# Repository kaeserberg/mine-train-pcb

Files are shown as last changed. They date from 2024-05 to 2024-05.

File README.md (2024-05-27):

# Le Train de la Mine - PCB

## Illustrations

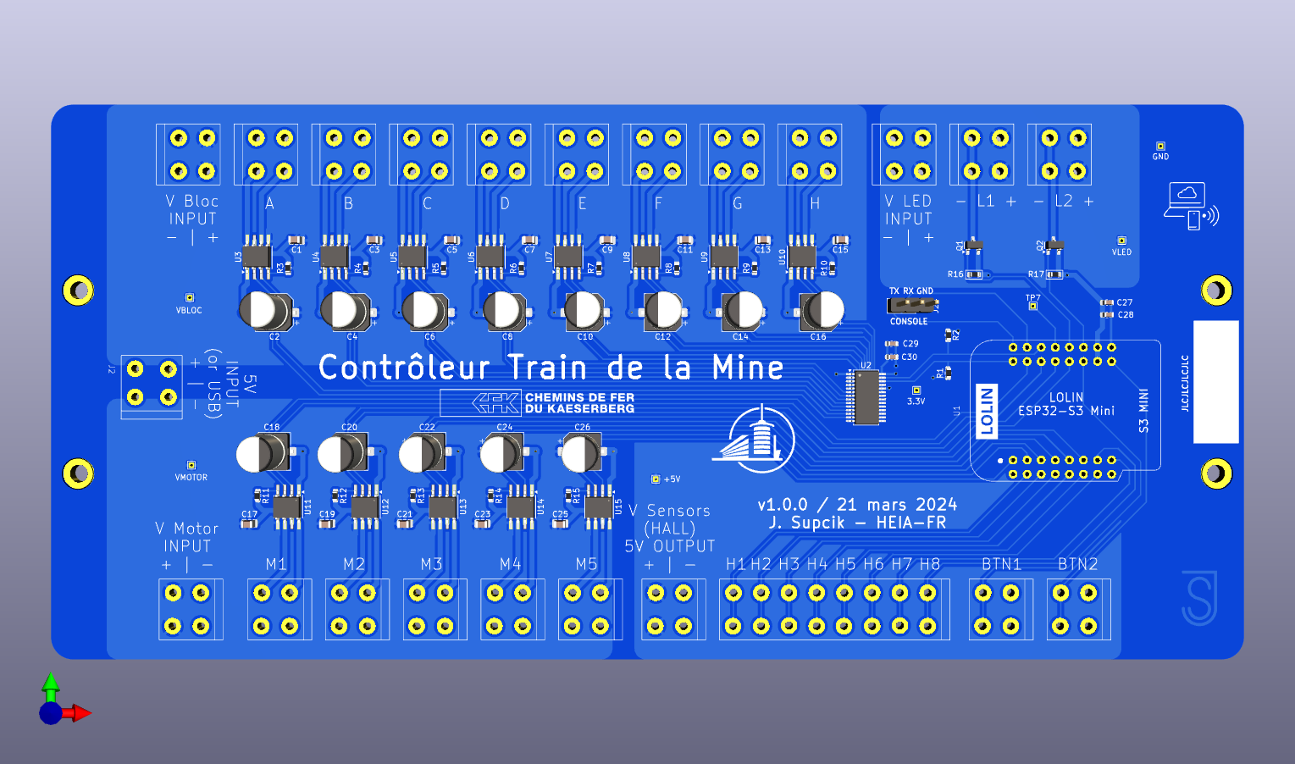
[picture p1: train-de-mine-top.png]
Dessus
<br/>
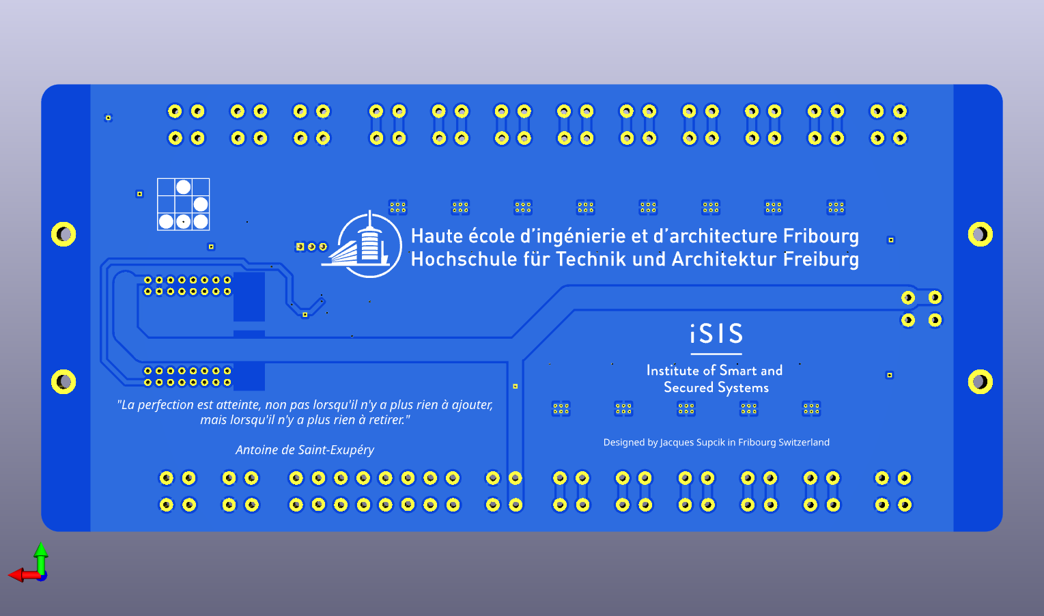
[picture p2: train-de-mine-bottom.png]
Desous


## Schéma

[Schéma électronique](train-de-mine-schematic.pdf)

## Commande de matériel

- [1 x 8p (1 x 12 pièces)](https://fr.aliexpress.com/item/1005005946834644.html)
- [3 x 2p (3 x 50 pièces)](https://fr.aliexpress.com/item/1005005946834644.html)
- [5x jeu de montage DRG-02](https://fr.aliexpress.com/item/32824633947.html)
- [5x rail DIN 30cm](https://fr.aliexpress.com/item/4001298414947.html)
- [5x ESP32-S3 Mini](https://fr.aliexpress.com/item/1005005449219195.html)
- [1x Connecteur femelle à 2x8 broches (50 pièces)](https://fr.aliexpress.com/item/32604411845.html)

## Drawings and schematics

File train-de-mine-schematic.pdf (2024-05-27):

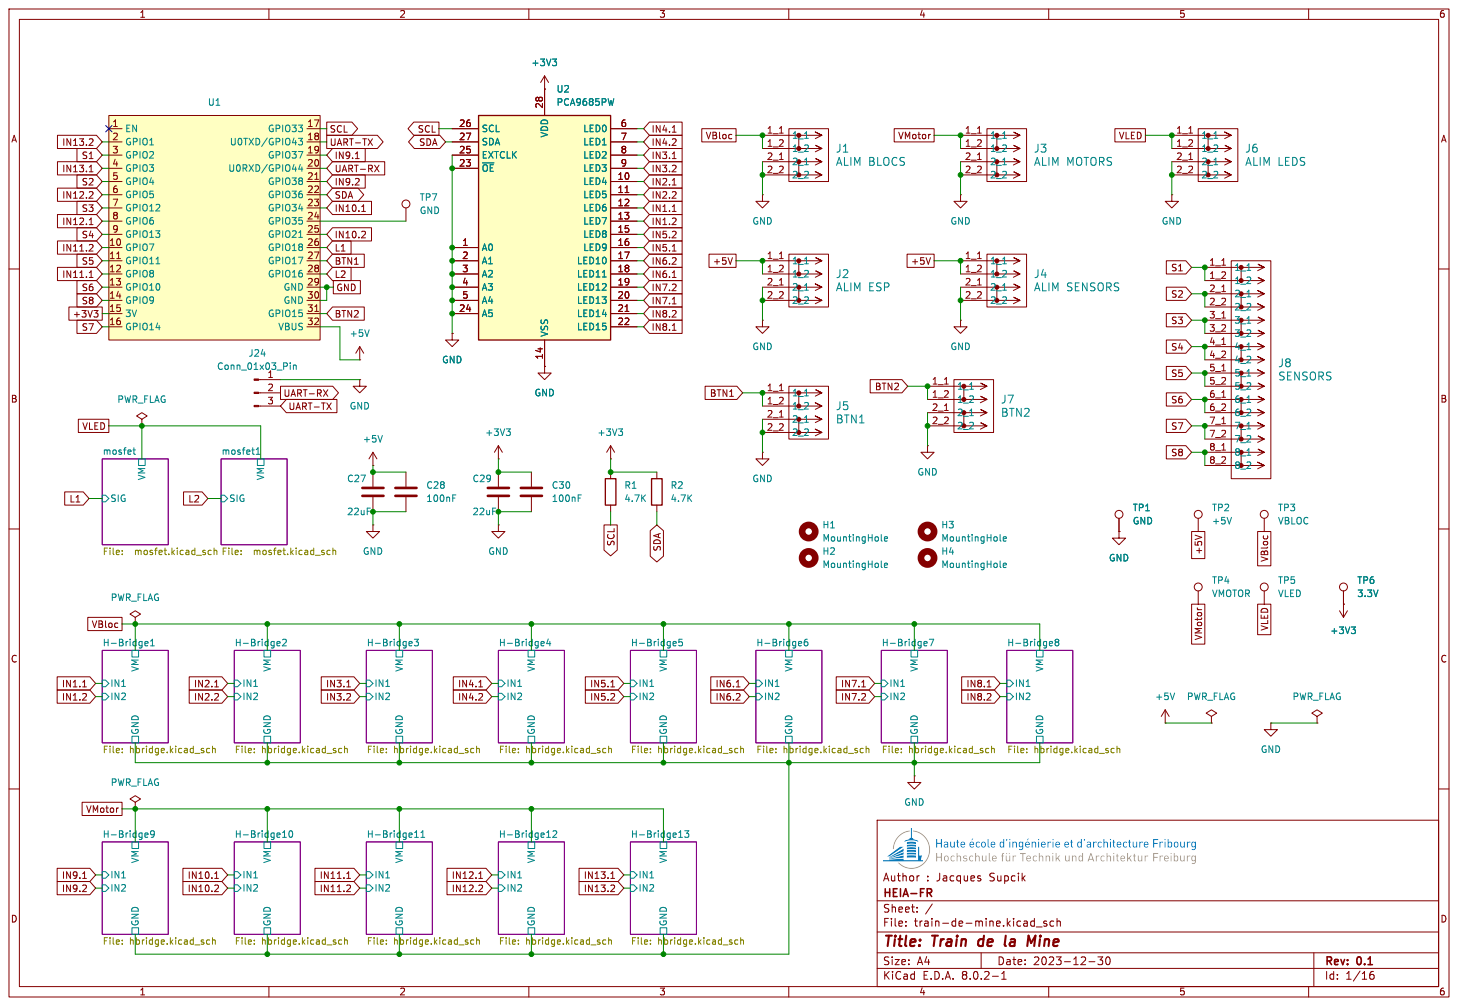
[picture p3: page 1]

Author : Jacques Supcik
File: train-de-mine.kicad_sch Sheet: / HEIA-FR

Id: 1/16 Title: Train de la Mine

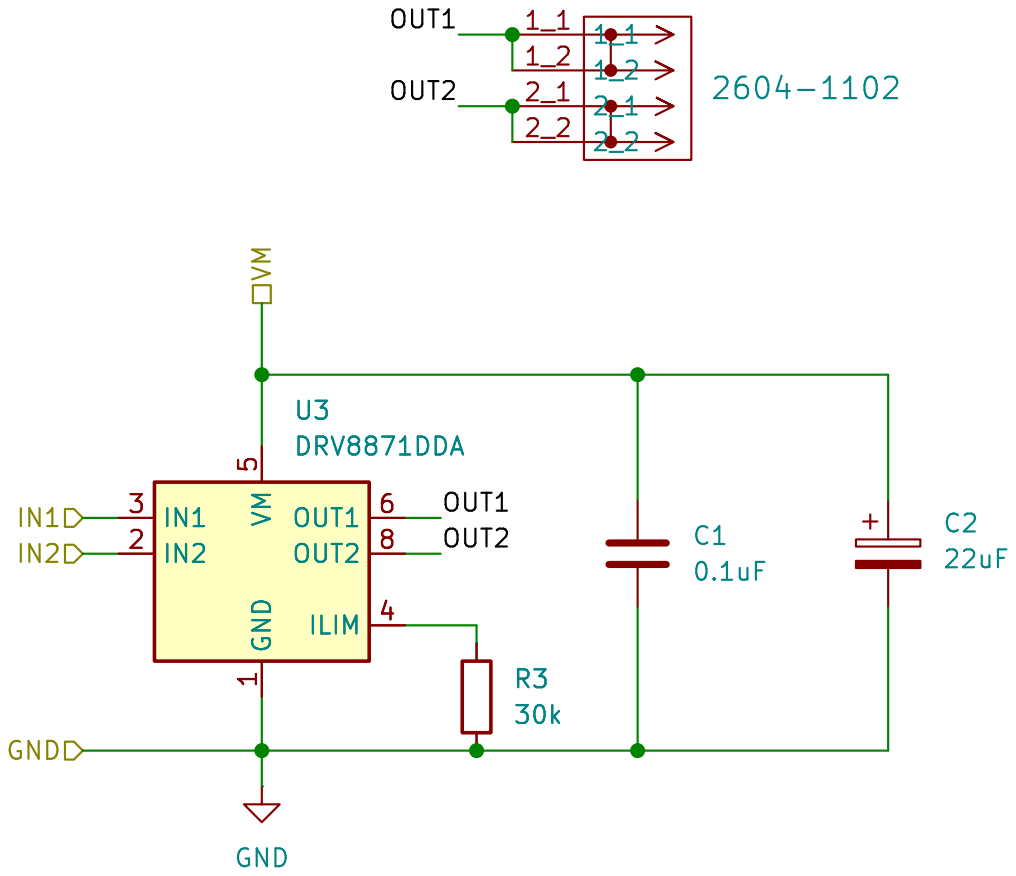
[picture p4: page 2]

Author: Jacques Supcik
File: hbridge.kicad_sch Sheet: /H-Bridge1/ HEIA-FR

Id: 2/16 Title: Train de la Mine : H-Bridge

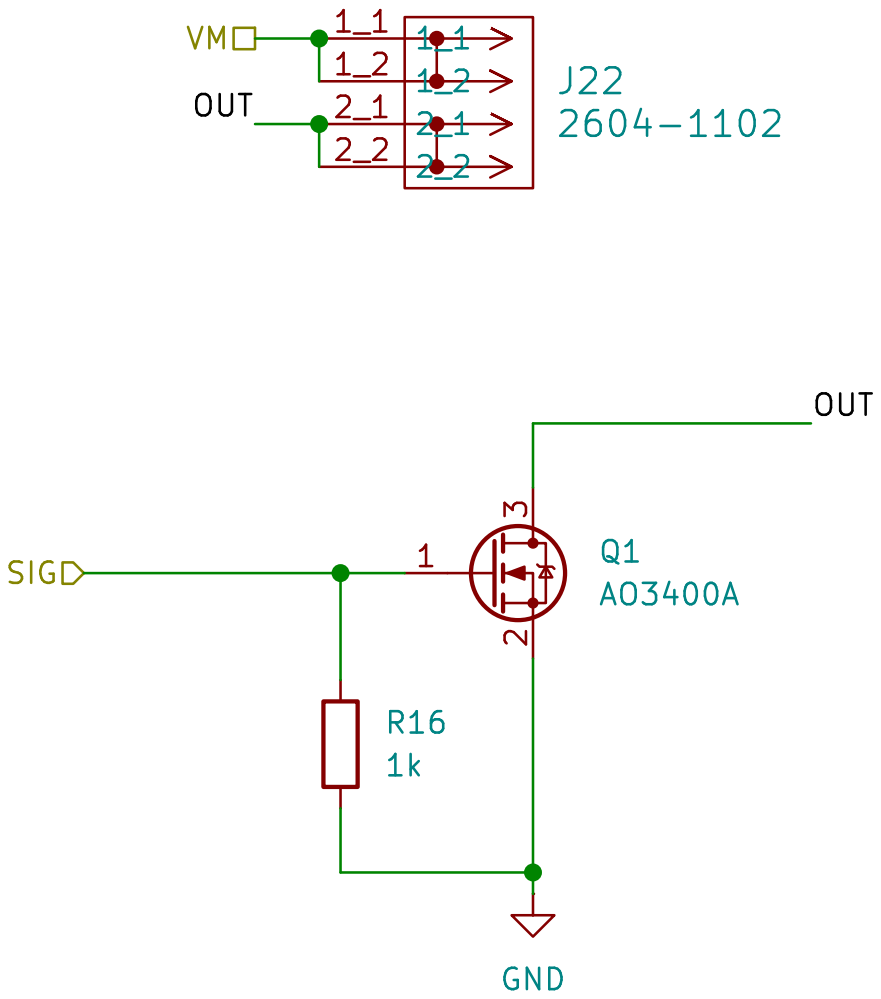
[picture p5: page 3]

Id: 15/16 Title: Train de la Mine : MOSFET

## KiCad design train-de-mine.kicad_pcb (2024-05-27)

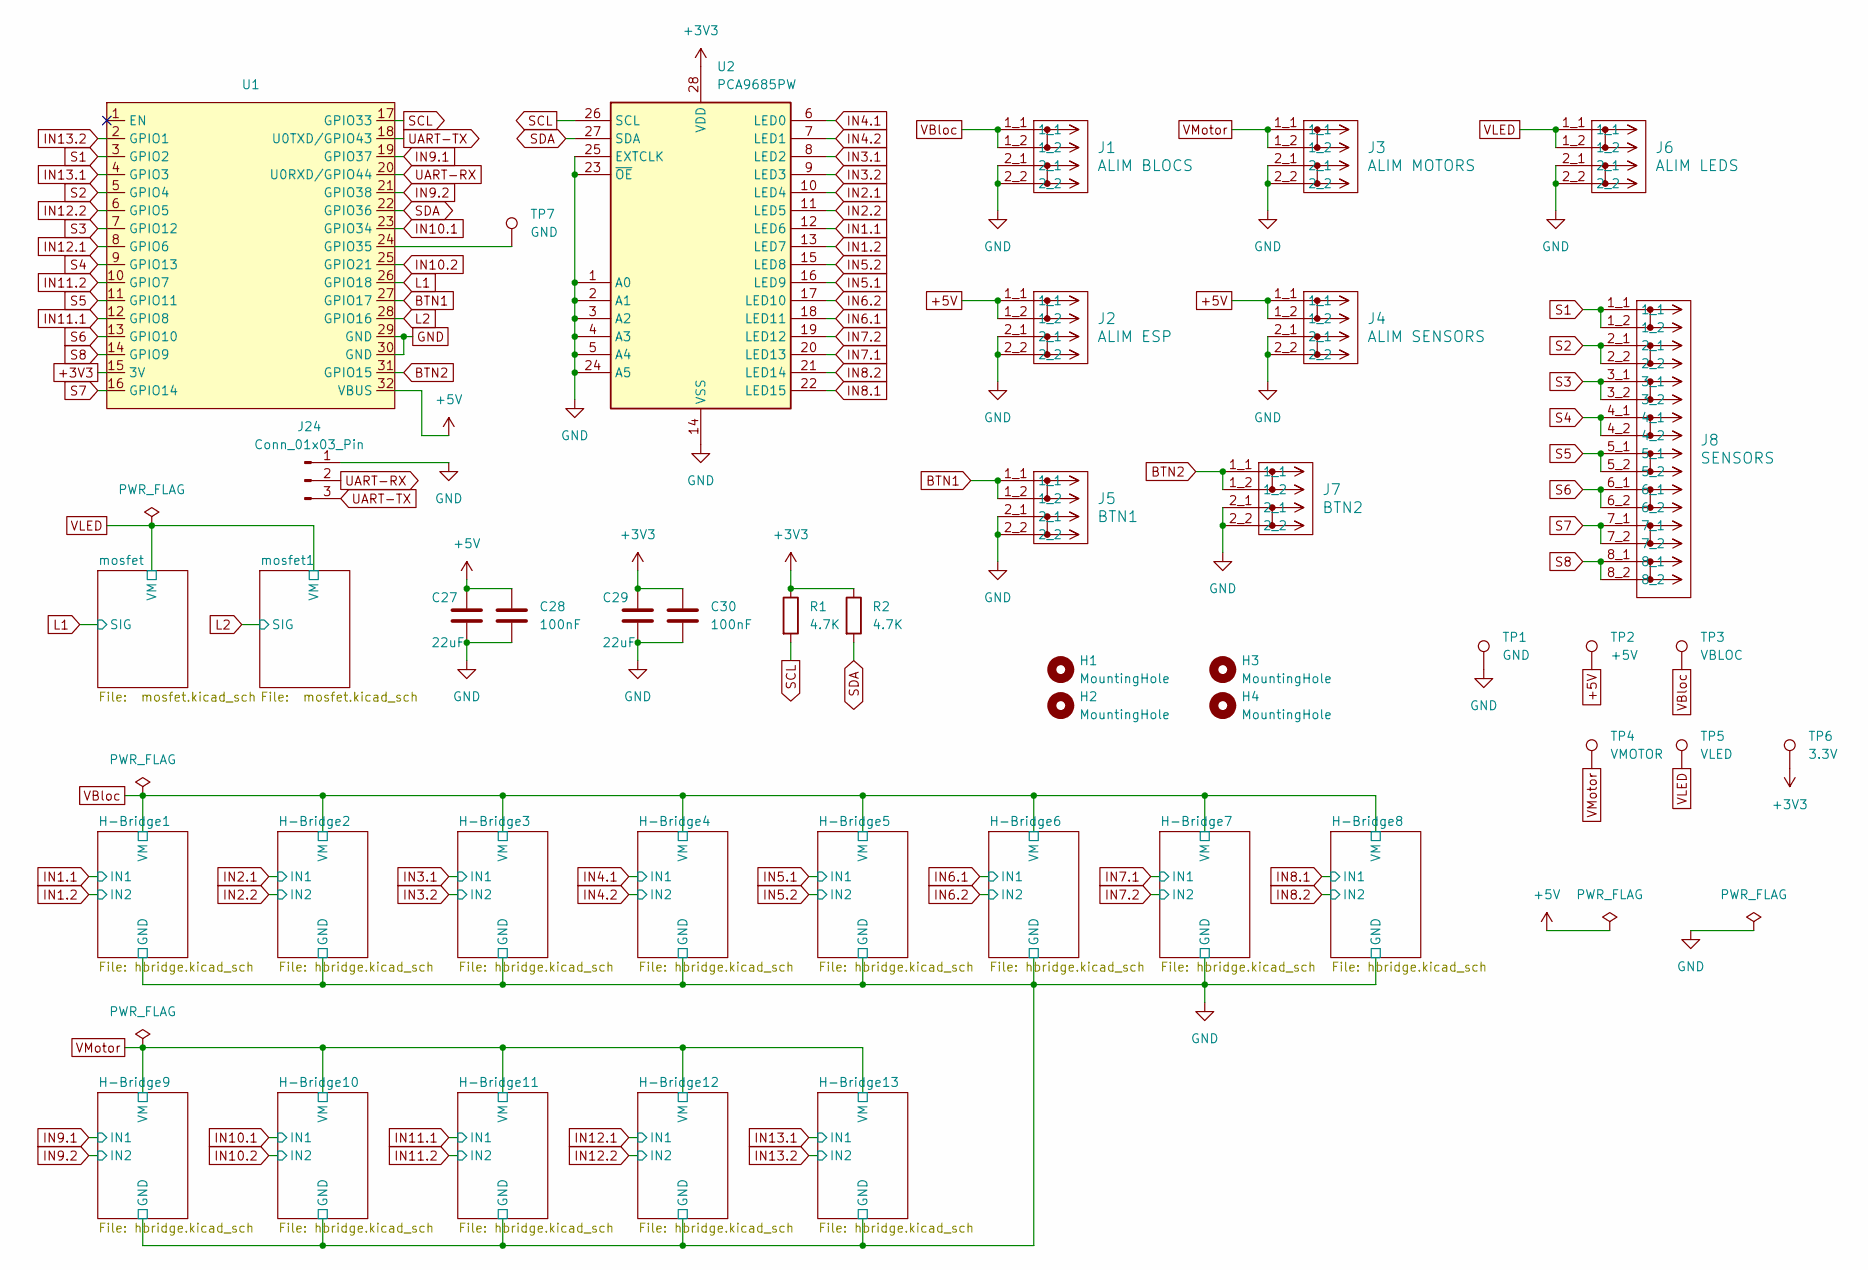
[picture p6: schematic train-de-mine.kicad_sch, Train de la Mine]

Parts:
C27, C29: 22uF; C_0603_1608Metric; LCSC C86295
C28, C30: 100nF; C_0603_1608Metric; LCSC C1591
H1, H2, H3, H4: MountingHole; MountingHole_3.2mm_M3_DIN965_Pad
J1: ALIM BLOCS; KFM736L-5.0-2P
J2: ALIM ESP; KFM736L-5.0-2P
J3: ALIM MOTORS; KFM736L-5.0-2P
J4: ALIM SENSORS; KFM736L-5.0-2P
J5: BTN1; KFM736L-5.0-2P
J6: ALIM LEDS; KFM736L-5.0-2P
J7: BTN2; KFM736L-5.0-2P
J8: SENSORS; KFM736L-5.0-8P
J24: Conn_01x03_Pin; PinHeader_1x03_P2.54mm_Vertical
R1, R2: 4.7K; R_0603_1608Metric; LCSC C23162
TP1, TP7: GND; TestPoint_THTPad_1.0x1.0mm_Drill0.5mm
TP2: +5V; TestPoint_THTPad_1.0x1.0mm_Drill0.5mm
TP3: VBLOC; TestPoint_THTPad_1.0x1.0mm_Drill0.5mm
TP4: VMOTOR; TestPoint_THTPad_1.0x1.0mm_Drill0.5mm
TP5: VLED; TestPoint_THTPad_1.0x1.0mm_Drill0.5mm
TP6: 3.3V; TestPoint_THTPad_1.0x1.0mm_Drill0.5mm
U1: 1; S3 Mini
U2: PCA9685PW; TSSOP-28_4.4x9.7mm_P0.65mm; LCSC C2678753

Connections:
+3V3: C29.1, C30.1, R1.1, R2.1, TP6.1, U1.15 (3V), U2.28 (VDD)
+5V: C27.1, C28.1, J2.1_1, J2.1_2, J4.1_1, J4.1_2, TP2.1, U1.32 (VBUS)
BTN1: J5.1_1, J5.1_2, U1.27 (GPIO17)
BTN2: J7.1_1, J7.1_2, U1.31 (GPIO15)
GND: C27.2, C28.2, C29.2, C30.2, J1.2_1, J1.2_2, J2.2_1, J2.2_2, J3.2_1, J3.2_2, J4.2_1, J4.2_2, J5.2_1, J5.2_2, J6.2_1, J6.2_2, J7.2_1, J7.2_2, J24.1, TP1.1, U1.29 (GND), U1.30 (GND), U2.1 (A0), U2.2 (A1), U2.3 (A2), U2.4 (A3), U2.5 (A4), U2.14 (VSS), U2.23 (~OE), U2.24 (A5), U2.25 (EXTCLK); also elsewhere on the board
IN1.1: U2.12 (LED6); also elsewhere on the board
IN1.2: U2.13 (LED7); also elsewhere on the board
IN2.1: U2.10 (LED4); also elsewhere on the board
IN2.2: U2.11 (LED5); also elsewhere on the board
IN3.1: U2.8 (LED2); also elsewhere on the board
IN3.2: U2.9 (LED3); also elsewhere on the board
IN4.1: U2.6 (LED0); also elsewhere on the board
IN4.2: U2.7 (LED1); also elsewhere on the board
IN5.1: U2.16 (LED9); also elsewhere on the board
IN5.2: U2.15 (LED8); also elsewhere on the board
IN6.1: U2.18 (LED11); also elsewhere on the board
IN6.2: U2.17 (LED10); also elsewhere on the board
IN7.1: U2.20 (LED13); also elsewhere on the board
IN7.2: U2.19 (LED12); also elsewhere on the board
IN8.1: U2.22 (LED15); also elsewhere on the board
IN8.2: U2.21 (LED14); also elsewhere on the board
IN9.1: U1.19 (GPIO37); also elsewhere on the board
IN9.2: U1.21 (GPIO38); also elsewhere on the board
IN10.1: U1.23 (GPIO34); also elsewhere on the board
IN10.2: U1.25 (GPIO21); also elsewhere on the board
IN11.1: U1.12 (GPIO8); also elsewhere on the board
IN11.2: U1.10 (GPIO7); also elsewhere on the board
IN12.1: U1.8 (GPIO6); also elsewhere on the board
IN12.2: U1.6 (GPIO5); also elsewhere on the board
IN13.1: U1.4 (GPIO3); also elsewhere on the board
IN13.2: U1.2 (GPIO1); also elsewhere on the board
unnamed: TP7.1, U1.24 (GPIO35)
S1: J8.1_1, J8.1_2, U1.3 (GPIO2)
S2: J8.2_1, J8.2_2, U1.5 (GPIO4)
S3: J8.3_1, J8.3_2, U1.7 (GPIO12)
S4: J8.4_1, J8.4_2, U1.9 (GPIO13)
S5: J8.5_1, J8.5_2, U1.11 (GPIO11)
S6: J8.6_1, J8.6_2, U1.13 (GPIO10)
S7: J8.7_1, J8.7_2, U1.16 (GPIO14)
S8: J8.8_1, J8.8_2, U1.14 (GPIO9)
SCL: R1.2, U1.17 (GPIO33), U2.26 (SCL)
SDA: R2.2, U1.22 (GPIO36), U2.27 (SDA)
UART-RX: J24.2, U1.20 (U0RXD/GPIO44)
UART-TX: J24.3, U1.18 (U0TXD/GPIO43)
VBloc: J1.1_1, J1.1_2, TP3.1; also elsewhere on the board
VLED: J6.1_1, J6.1_2, TP5.1; also elsewhere on the board
VMotor: J3.1_1, J3.1_2, TP4.1; also elsewhere on the board

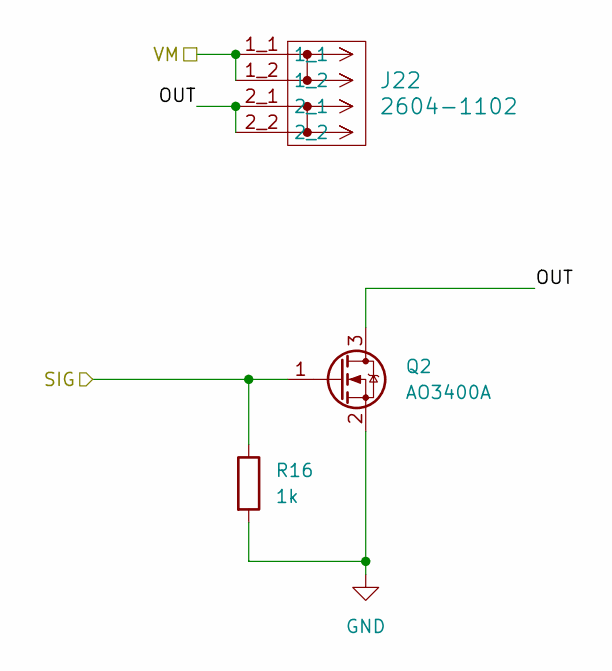
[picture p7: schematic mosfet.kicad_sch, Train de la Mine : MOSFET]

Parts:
J22: 2604-1102; KFM736L-5.0-2P
Q2: AO3400A; SOT-23; LCSC C347475
R16: 1k; R_0603_1608Metric; LCSC C21190

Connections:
GND: Q2.2 (S), R16.2; also elsewhere on the board
VLED: J22.1_1, J22.1_2; also elsewhere on the board

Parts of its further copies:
J23: 2604-1102; KFM736L-5.0-2P
Q1: AO3400A; SOT-23; LCSC C347475
R17: 1k; R_0603_1608Metric; LCSC C21190

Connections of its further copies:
GND: Q1.2 (S), R17.2; also elsewhere on the board
VLED: J23.1_1, J23.1_2; also elsewhere on the board

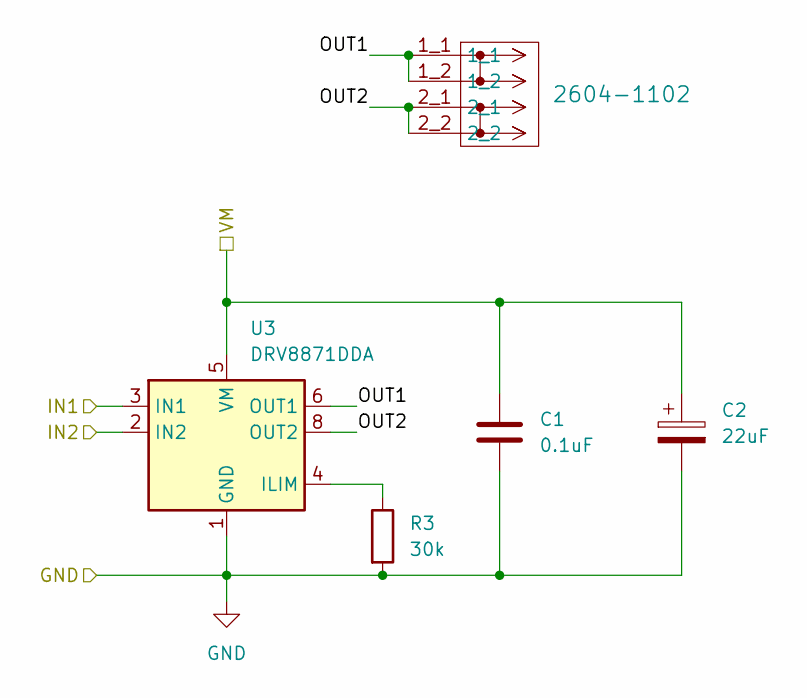
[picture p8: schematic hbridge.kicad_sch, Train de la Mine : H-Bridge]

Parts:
C1: 0.1uF; C_0805_2012Metric; LCSC C49678
C2: 22uF; CP_Elec_6.3x7.7; LCSC C242074
J9: 2604-1102; KFM736L-5.0-2P
R3: 30k; R_0603_1608Metric; LCSC C22984
U3: DRV8871DDA; Texas_HTSOP-8-1EP_3.9x4.9mm_P1.27mm_EP2.95x4.9mm_Mask2.4x3.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; LCSC C75864

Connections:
/H-Bridge1/OUT1: J9.1_1, J9.1_2, U3.6 (OUT1)
/H-Bridge1/OUT2: J9.2_1, J9.2_2, U3.8 (OUT2)
GND: C1.2, C2.2, R3.2, U3.1 (GND), U3.7 (GND), U3.9 (GND); also elsewhere on the board
IN1.1: U3.3 (IN1); also elsewhere on the board
IN1.2: U3.2 (IN2); also elsewhere on the board
unnamed: R3.1, U3.4 (ILIM)
VBloc: C1.1, C2.1, U3.5 (VM); also elsewhere on the board

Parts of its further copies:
C3, C5, C7, C9, C11, C13, C15, C17, C19, C21, C23, C25: 0.1uF; C_0805_2012Metric; LCSC C49678
C4, C6, C8, C10, C12, C14, C16, C18, C20, C22, C24, C26: 22uF; CP_Elec_6.3x7.7; LCSC C242074
J10, J11, J12, J13, J14, J15, J16, J17, J18, J19, J20, J21: 2604-1102; KFM736L-5.0-2P
R4, R5, R6, R7, R8, R9, R10, R11, R12, R13, R14, R15: 30k; R_0603_1608Metric; LCSC C22984
U4, U5, U6, U7, U8, U9, U10, U11, U12, U13, U14, U15: DRV8871DDA; Texas_HTSOP-8-1EP_3.9x4.9mm_P1.27mm_EP2.95x4.9mm_Mask2.4x3.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; LCSC C75864

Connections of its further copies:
/H-Bridge2/OUT1: J10.1_1, J10.1_2, U4.6 (OUT1)
/H-Bridge2/OUT2: J10.2_1, J10.2_2, U4.8 (OUT2)
/H-Bridge3/OUT1: J11.1_1, J11.1_2, U5.6 (OUT1)
/H-Bridge3/OUT2: J11.2_1, J11.2_2, U5.8 (OUT2)
/H-Bridge4/OUT1: J12.1_1, J12.1_2, U6.6 (OUT1)
/H-Bridge4/OUT2: J12.2_1, J12.2_2, U6.8 (OUT2)
/H-Bridge5/OUT1: J13.1_1, J13.1_2, U7.6 (OUT1)
/H-Bridge5/OUT2: J13.2_1, J13.2_2, U7.8 (OUT2)
/H-Bridge6/OUT1: J14.1_1, J14.1_2, U8.6 (OUT1)
/H-Bridge6/OUT2: J14.2_1, J14.2_2, U8.8 (OUT2)
/H-Bridge7/OUT1: J15.1_1, J15.1_2, U9.6 (OUT1)
/H-Bridge7/OUT2: J15.2_1, J15.2_2, U9.8 (OUT2)
/H-Bridge8/OUT1: J16.1_1, J16.1_2, U10.6 (OUT1)
/H-Bridge8/OUT2: J16.2_1, J16.2_2, U10.8 (OUT2)
/H-Bridge9/OUT1: J17.1_1, J17.1_2, U11.6 (OUT1)
/H-Bridge9/OUT2: J17.2_1, J17.2_2, U11.8 (OUT2)
/H-Bridge10/OUT1: J18.1_1, J18.1_2, U12.6 (OUT1)
/H-Bridge10/OUT2: J18.2_1, J18.2_2, U12.8 (OUT2)
/H-Bridge11/OUT1: J19.1_1, J19.1_2, U13.6 (OUT1)
/H-Bridge11/OUT2: J19.2_1, J19.2_2, U13.8 (OUT2)
/H-Bridge12/OUT1: J20.1_1, J20.1_2, U14.6 (OUT1)
/H-Bridge12/OUT2: J20.2_1, J20.2_2, U14.8 (OUT2)
/H-Bridge13/OUT1: J21.1_1, J21.1_2, U15.6 (OUT1)
/H-Bridge13/OUT2: J21.2_1, J21.2_2, U15.8 (OUT2)
GND: C3.2, C4.2, C5.2, C6.2, C7.2, C8.2, C9.2, C10.2, C11.2, C12.2, C13.2, C14.2, C15.2, C16.2, C17.2, C18.2, C19.2, C20.2, C21.2, C22.2, C23.2, C24.2, C25.2, C26.2, R4.2, R5.2, R6.2, R7.2, R8.2, R9.2, R10.2, R11.2, R12.2, R13.2, R14.2, R15.2, U4.1 (GND), U4.7 (GND), U4.9 (GND), U5.1 (GND), U5.7 (GND), U5.9 (GND), U6.1 (GND), U6.7 (GND), U6.9 (GND), U7.1 (GND), U7.7 (GND), U7.9 (GND), U8.1 (GND), U8.7 (GND), U8.9 (GND), U9.1 (GND), U9.7 (GND), U9.9 (GND), U10.1 (GND), U10.7 (GND), U10.9 (GND), U11.1 (GND), U11.7 (GND), U11.9 (GND), U12.1 (GND), U12.7 (GND), U12.9 (GND), U13.1 (GND), U13.7 (GND), U13.9 (GND), U14.1 (GND), U14.7 (GND), U14.9 (GND), U15.1 (GND), U15.7 (GND), U15.9 (GND); also elsewhere on the board
IN2.1: U4.3 (IN1); also elsewhere on the board
IN2.2: U4.2 (IN2); also elsewhere on the board
IN3.1: U5.3 (IN1); also elsewhere on the board
IN3.2: U5.2 (IN2); also elsewhere on the board
IN4.1: U6.3 (IN1); also elsewhere on the board
IN4.2: U6.2 (IN2); also elsewhere on the board
IN5.1: U7.3 (IN1); also elsewhere on the board
IN5.2: U7.2 (IN2); also elsewhere on the board
IN6.1: U8.3 (IN1); also elsewhere on the board
IN6.2: U8.2 (IN2); also elsewhere on the board
IN7.1: U9.3 (IN1); also elsewhere on the board
IN7.2: U9.2 (IN2); also elsewhere on the board
IN8.1: U10.3 (IN1); also elsewhere on the board
IN8.2: U10.2 (IN2); also elsewhere on the board
IN9.1: U11.3 (IN1); also elsewhere on the board
IN9.2: U11.2 (IN2); also elsewhere on the board
IN10.1: U12.3 (IN1); also elsewhere on the board
IN10.2: U12.2 (IN2); also elsewhere on the board
IN11.1: U13.3 (IN1); also elsewhere on the board
IN11.2: U13.2 (IN2); also elsewhere on the board
IN12.1: U14.3 (IN1); also elsewhere on the board
IN12.2: U14.2 (IN2); also elsewhere on the board
IN13.1: U15.3 (IN1); also elsewhere on the board
IN13.2: U15.2 (IN2); also elsewhere on the board
unnamed: R4.1, U4.4 (ILIM)
unnamed: R5.1, U5.4 (ILIM)
unnamed: R6.1, U6.4 (ILIM)
unnamed: R7.1, U7.4 (ILIM)
unnamed: R8.1, U8.4 (ILIM)
unnamed: R9.1, U9.4 (ILIM)
unnamed: R10.1, U10.4 (ILIM)
unnamed: R11.1, U11.4 (ILIM)
unnamed: R12.1, U12.4 (ILIM)
unnamed: R13.1, U13.4 (ILIM)
unnamed: R14.1, U14.4 (ILIM)
unnamed: R15.1, U15.4 (ILIM)
VBloc: C3.1, C4.1, C5.1, C6.1, C7.1, C8.1, C9.1, C10.1, C11.1, C12.1, C13.1, C14.1, C15.1, C16.1, U4.5 (VM), U5.5 (VM), U6.5 (VM), U7.5 (VM), U8.5 (VM), U9.5 (VM), U10.5 (VM); also elsewhere on the board
VMotor: C17.1, C18.1, C19.1, C20.1, C21.1, C22.1, C23.1, C24.1, C25.1, C26.1, U11.5 (VM), U12.5 (VM), U13.5 (VM), U14.5 (VM), U15.5 (VM); also elsewhere on the board

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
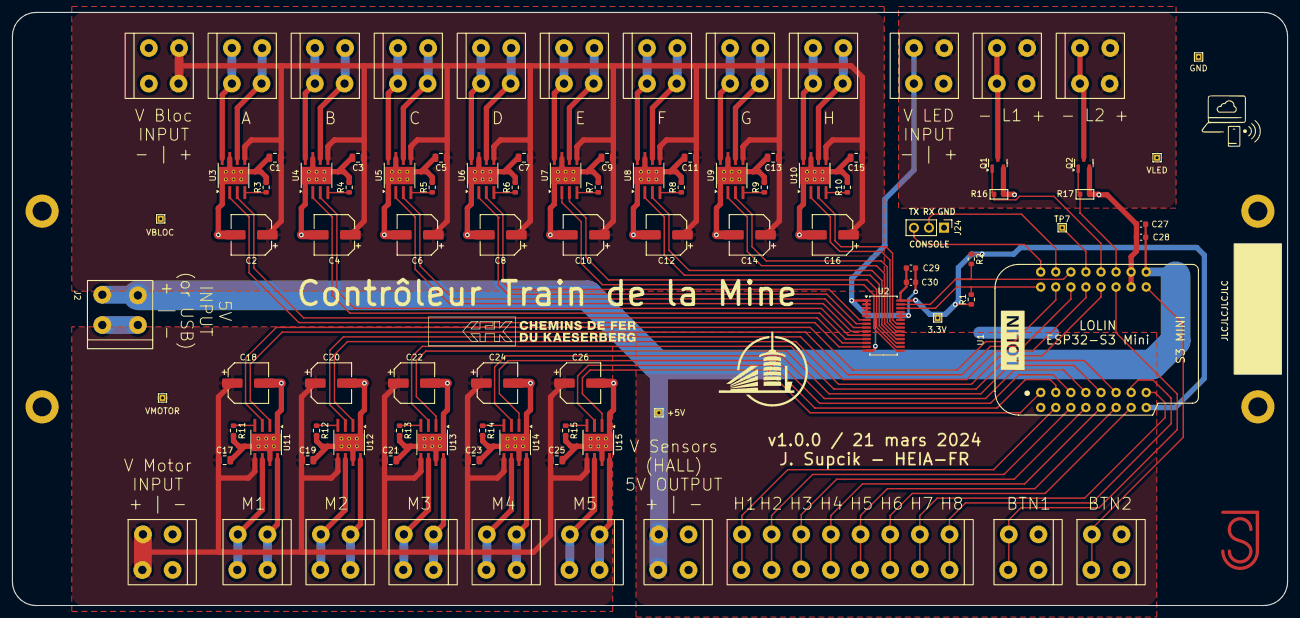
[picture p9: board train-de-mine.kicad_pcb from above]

Board: 2 copper layers, 215.0 x 100.0 mm, 100 parts (0 on the bottom side), 90 nets.

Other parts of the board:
CFK Logo: LOGO
